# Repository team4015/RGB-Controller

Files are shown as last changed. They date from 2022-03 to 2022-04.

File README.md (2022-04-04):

# RGB Controller
Hardware and firmware for controlling LED RGB strips on FRC robots.

## Protocol

The RGB Controller circuit board contains a PIC16F690 microcontroller that sets the RGB colour using PWM signals.  The PIC runs the C firmware found in the `firmware` folder.  The RoboRIO can talk to the PIC using the following specific protocol:

By default, the PIC waits for the byte `0xFF` on its RX line.  Any other bytes will be discarded.  Once the PIC receives the `0xFF` header byte, it will receive three more bytes from the RX line.  These three bytes are used as the RGB brightness values.  Therefore, so set the RGB colour, the RoboRIO must send a total of 4 bytes:

```python
header = 0xFF

# RGB values must be between 0 and 255
red = 128
green = 255
blue = 0

packet = [header, red, green, blue]
send(packet)
```

**NOTE:** The PIC will never respond to the RoboRIO by sending back data.  Lights are a non-critical feature of the robot so the RoboRIO should not sit around waiting for the PIC to respond.

# Serial Port

The PIC communicates with the RoboRIO over UART, using only the TX and RX lines.  You will also need to connect the GND lines between the RGB controller board and the serial port on the RoboRIO.  The baud rate must be `9600` bps (the exact baud rate is `9615` if you want to be super precise).  No parity bits are used.  The size of one byte must be 8 bits.

**IMPORTANT:**  The PIC cannot receive more than one byte at a time.  Therefore, make sure that the RoboRIO sends data one byte at a time, with a delay of 1.5 ms between each byte.  It is advised to flush the serial port TX buffer after writing each byte.  See the Python script `rgb.py` under `firmware` for an example.

# Python Test Scripts

There are two Python test scripts: `rgb.py` and `rainbow.py`.  `rgb.py` is used to set a specific RGB colour once.  `rainbow.py` will run through the colour spectrum.

First install `pyserial`:
```
pip3 install pyserial
```

To run `rgb.py`:
```
python3 rgb.py <red> <green> <blue>
```
`red`, `green`, and `blue` must be values from `0` to `255`.

To run `rainbow.py`:
```
python3 rainbow.py
```

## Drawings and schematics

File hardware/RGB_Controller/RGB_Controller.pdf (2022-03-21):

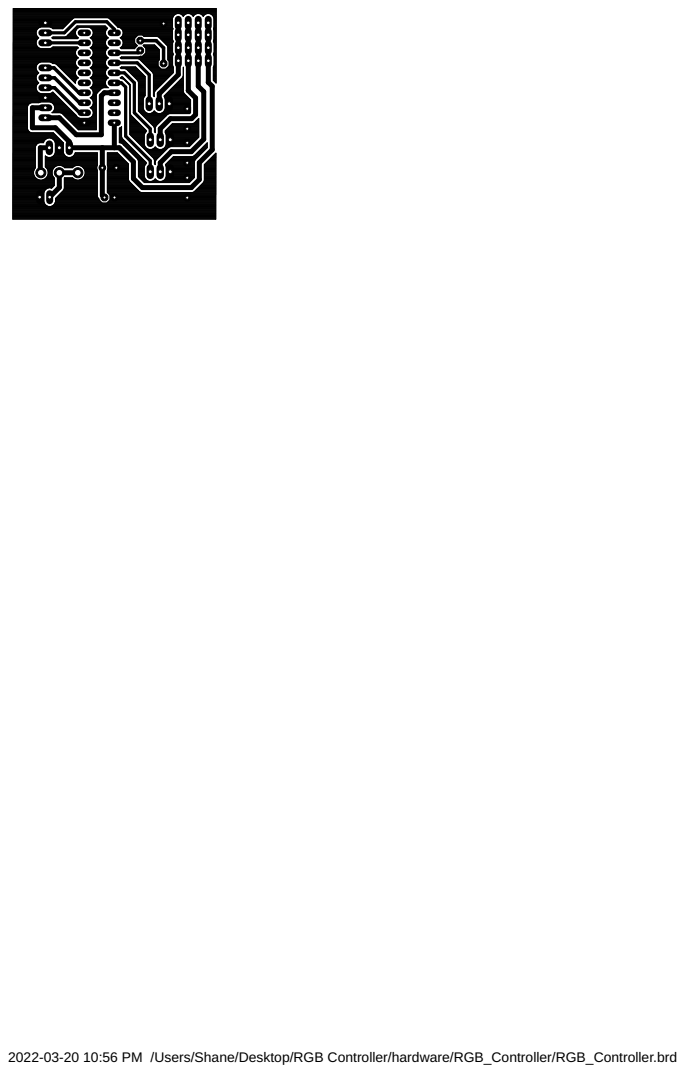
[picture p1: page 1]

2022-03-20 10:56 PM /Users/Shane/Desktop/RGB Controller/hardware/RGB_Controller/RGB_Controller.brd

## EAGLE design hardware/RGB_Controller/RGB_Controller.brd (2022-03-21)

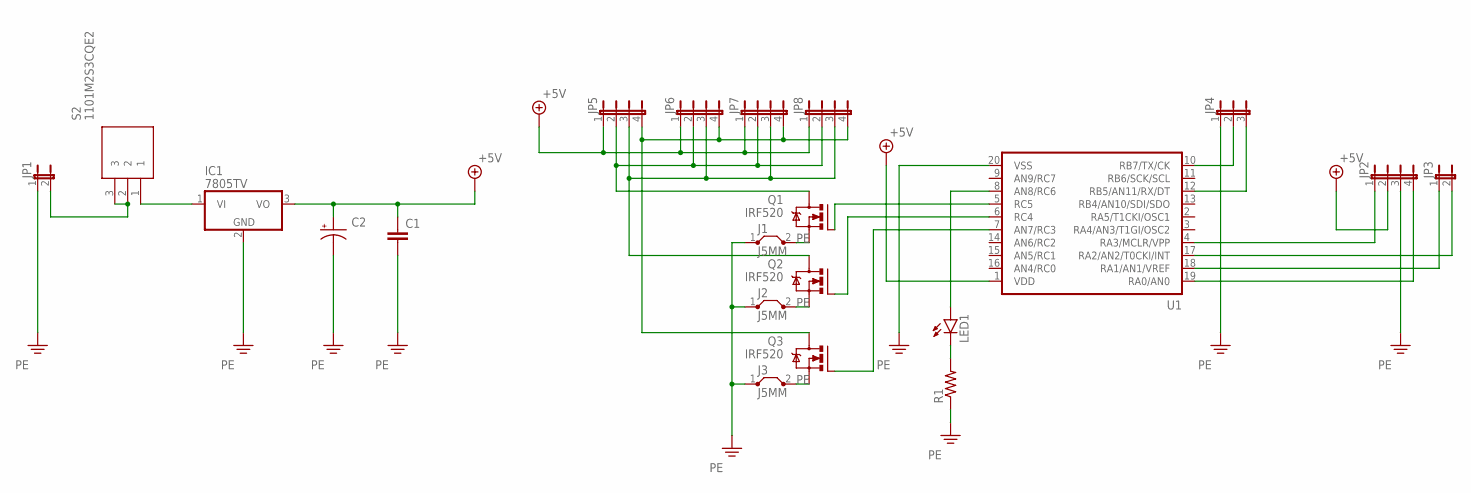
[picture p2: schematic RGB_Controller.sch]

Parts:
C1: C-EU025-024X044; C025-024X044
C2: CPOL-USE3.5-10; E3,5-10
IC1: 7805TV; TO220V
J1, J2, J3: J5MM; 05
JP1, JP3: JP1E; JP1
JP2, JP5, JP6, JP7, JP8: JP4E; JP4
JP4: JP2E; JP2
LED1: LED5MM
Q1, Q2, Q3: IRF520; TO220BV
R1: R-US_0207/10; 0207/10
S2: 1101M2S3CQE2; 1000-SERIES(SPDT)
U1: PIC16F6XX; DIL20

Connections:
+5V: C1.1, C2.+, IC1.3 (VO), JP2.2, JP5.1, JP6.1, JP7.1, JP8.1, U1.1 (VDD)
unnamed: JP1.2, S2.2, S2.3
unnamed: JP2.1, U1.4 (RA3/MCLR/VPP)
unnamed: LED1.K (C), R1.2
unnamed: JP2.4, U1.19 (RA0/AN0)
unnamed: JP3.1, U1.18 (RA1/AN1/VREF)
unnamed: JP3.2, U1.17 (RA2/AN2/T0CKI/INT)
unnamed: JP4.2, U1.10 (RB7/TX/CK)
unnamed: JP4.3, U1.12 (RB5/AN11/RX/DT)
unnamed: Q1.G, U1.5 (RC5)
unnamed: Q2.G, U1.6 (RC4)
unnamed: Q3.G, U1.7 (AN7/RC3)
unnamed: JP5.2, JP6.2, JP7.2, JP8.2, Q1.D
unnamed: JP5.3, JP6.3, JP7.3, JP8.3, Q2.D
unnamed: JP5.4, JP6.4, JP7.4, JP8.4, Q3.D
unnamed: LED1.A, U1.8 (AN8/RC6)
unnamed: IC1.1 (VI), S2.1
PE: C1.2, C2.-, IC1.2 (GND), J1.1, J1.2, J2.1, J2.2, J3.1, J3.2, JP1.1, JP2.3, JP4.1, Q1.S, Q2.S, Q3.S, R1.1, U1.20 (VSS)

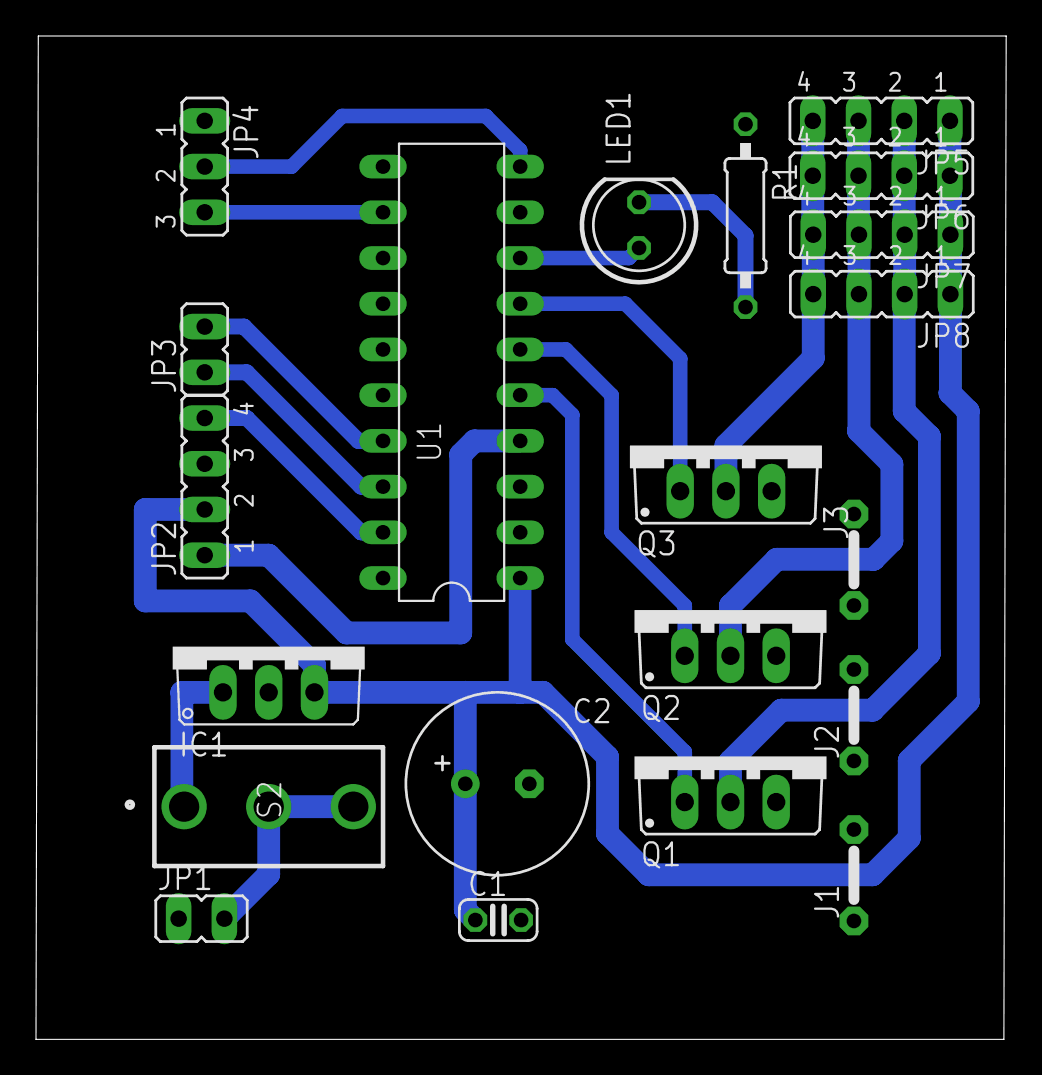
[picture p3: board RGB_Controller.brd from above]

Board: 2 copper layers, 53.9 x 55.7 mm, 21 parts (0 on the bottom side), 18 nets.

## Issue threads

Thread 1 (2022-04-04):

Fix schematic if L7805 is removed

bricktrooper, 2022-04-04:
This must be fixed in both the schematic and the board.

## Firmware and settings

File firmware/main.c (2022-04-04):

/* ======= RGB CONTROLLER =======
 * The protocol for talking to the
 * RGB controller is very simple.
 * The PIC will look for a header
 * byte '0xFF' AKA eight 1's.  When
 * this byte is detected, the PIC will
 * receive the next three bytes from the
 * UART and use them as the RGB values.
 * These bytes will be should be the
 * brightness values for red, green,
 * and blue, in that order.  The status
 * LED will turn on while the RGB values
 * are being received.  The PIC will
 * will never respond to the sender.
 *
 * IMPORTANT:
 * Please note that the PIC UART can
 * only receive one or two bytes at a
 * time in the RX buffer.  Sending more
 * than one byte all at once will
 * drown the PIC in bytes.  Please
 * transmit bytes individually to the
 * PIC with a delay of 10 ms between
 * each one.
 * ============================== */

#include <xc.h>
#include <pic16f690.h>

#include "init.h"
#include "led.h"
#include "uart.h"
#include "pwm.h"

#define HEADER   0xFF
#define FLASH_DELAY   10000000

inline void rgb(unsigned char red, unsigned char green, unsigned char blue)
{
	pwm_red(red);
	pwm_green(green);
	pwm_blue(blue);
}

inline void purple(void)
{
	rgb(200, 0, 128);
}

void main(void)
{
	init_hardware();
	led_init();
	uart_init();
	pwm_init();

	purple();

	while (1)
	{
		while (uart_receive_byte() != HEADER);   // wait for the header byte on the UART

		led_on();

		// receive the RGB values
		char red = uart_receive_byte();
		char green = uart_receive_byte();
		char blue = uart_receive_byte();

		led_off();

		// update the brightness for each colour
		rgb(red, green, blue);
	}
}

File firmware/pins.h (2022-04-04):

#ifndef PINS_H
#define PINS_H

// STATUS LED //

#define LED        RC6
#define LED_TRIS   TRISC6

// RGB LEDS //

#define RED     RC4
#define GREEN   RC5
#define BLUE    RC3

#define RED_TRIS     TRISC4
#define GREEN_TRIS   TRISC5
#define BLUE_TRIS    TRISC3

#endif /* PINS_H */

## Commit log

2022-03-07 LED code
2022-03-07 PWM attempt with Timer0
2022-03-07 Use Timer2 instead because it's faster
2022-03-07 20 kHz PWM refresh rate with useable UART
2022-03-07 API for setting RGB PWM colours
2022-03-07 Go back to 10 kHz interrupt to avoid UART starvation
    [pwm.c]
2022-03-07 Clean up UART
2022-03-07 Receive RGB values over UART
2022-03-07 Reset counters when setting brightness
    [pwm.c]
2022-03-17 Completed Hardware Files
    - Completed schematic and board design
    [RGB_Controller.brd, RGB_Controller.sch]
2022-03-18 Fixed Colour Inconsistency
    - Changed flushOutput() from serial to flush() function
    [RGB_Controller.brd, RGB_Controller.sch]
2022-03-19 Don't reset counters when setting new brightness
    [pwm.c]
2022-03-21 Added Sip Pins
    [RGB_Controller.brd, RGB_Controller.sch]
2022-04-04 Bump to 8 MHz and back off on interrupt frequency
2022-04-04 Swap green and blue pins
    [init.c, main.c, pins.h]
